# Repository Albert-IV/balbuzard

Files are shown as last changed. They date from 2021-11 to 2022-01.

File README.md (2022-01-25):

# Balbuzard

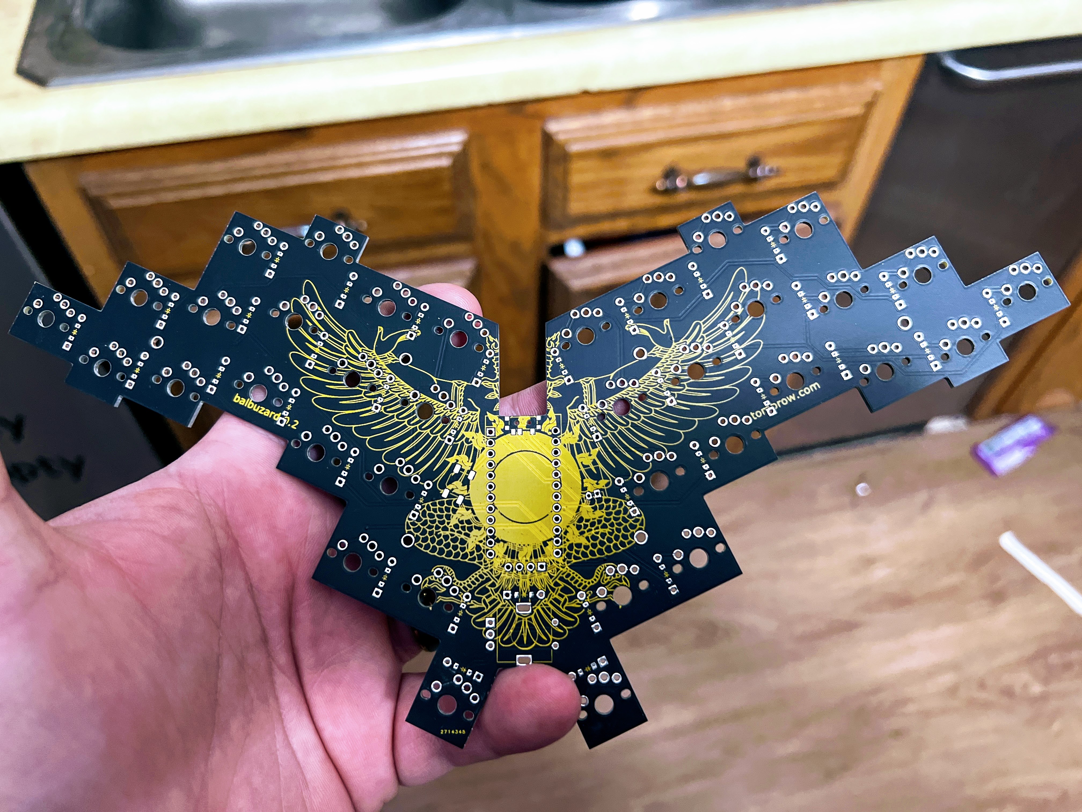
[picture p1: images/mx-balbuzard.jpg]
photo of assembled keyboard


Balbuzard is a 36-key keyboard with a PCB. This repository contains the [Ergogen](https://github.com/mrzealot/ergogen) configuration that generates the KiCad PCB file.

## Usage

Assuming you have [npm installed](https://www.npmjs.com/get-npm):

``` sh
git clone --recursive git@github.com:brow/balbuzard.git
cd balbuzard
make
```

Find the generated PCB at `output/pcbs/main.kicad_pcb`.

pcb thumbnail image

## How do you type on that?

My keymap looks like this. The colors indicate which finger I use to hit each key.

example keymap

## Rev 1.

* Ergogen config upgraded to latest 3.0.0
* Column layout tweaked, ready for routuing
* Each key / diode is routed.  Next is to route columns and rows (AKA the hard part)
* Removed routing done since I've found a way in Kicad to make direct connections (which will make the key routing cleaner looking)
* Redid the key / diode routing to use straight tracks wherever I could. 
* Just went ahead and used [an autorouter called Freerouter.](https://github.com/freerouting/freerouting/)
* After much gnashing of teeth, I have the scales SVG working.  Now to add to the front / back of PCB.

Front SVG Export:
Edge.Cuts
F.Silkscreen
F.Mask

Back SVG Export:
Edge.Cuts
B.Silkscreen
B.Mask

# TODO

* Add Balbuzard silkscreen on the front of the PCB
* Add something to the back of the PCB?  Thinking maybe a pattern like this: https://pattern.monster/scales-3/

**Note:** If there is a Rev 2. you will need to rotate the left side buttom-most thumb key's diode.  Rotated manually in Kicad to make it easier to route without routing on the back side.

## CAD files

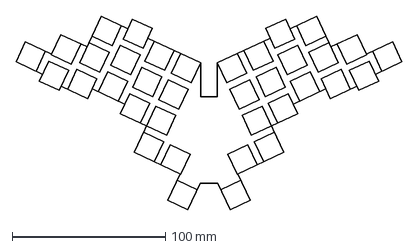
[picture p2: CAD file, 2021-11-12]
output/outlines/mockup.dxf
251.9 x 126.1 mm

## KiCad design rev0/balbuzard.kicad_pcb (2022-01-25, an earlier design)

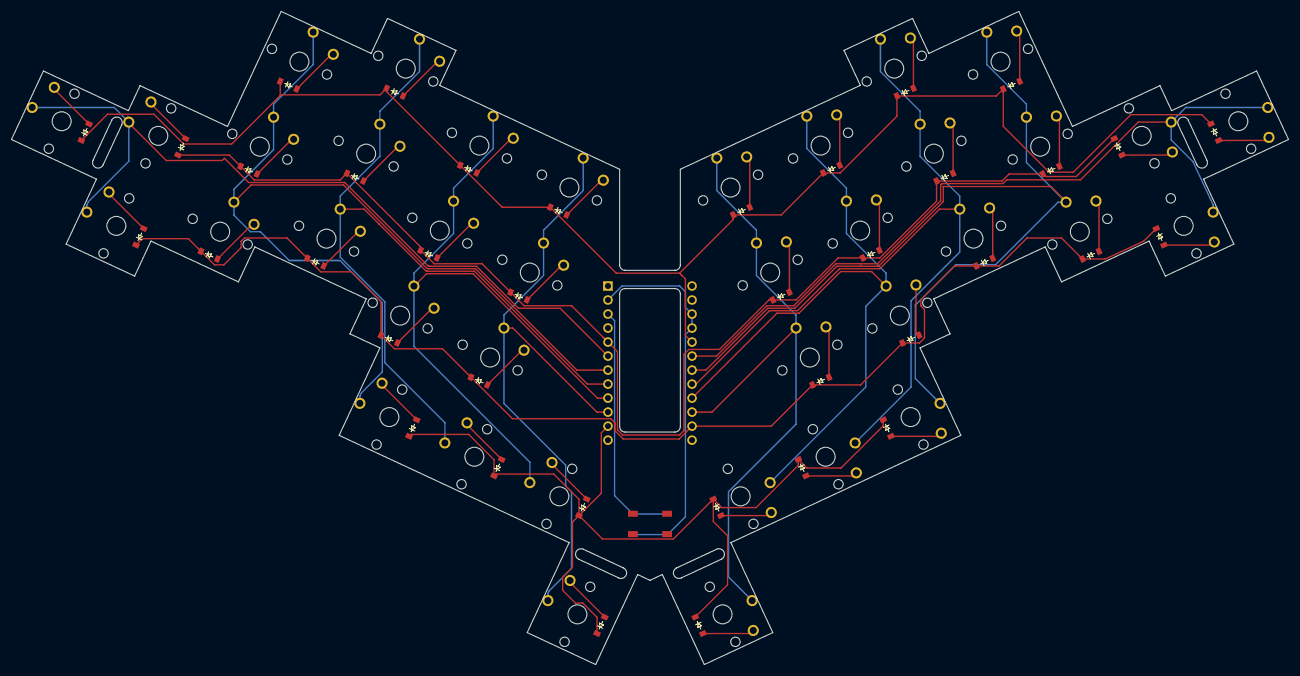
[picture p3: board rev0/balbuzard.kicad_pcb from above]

Board: 2 copper layers, 231.5 x 118.4 mm, 77 parts (0 on the bottom side), 52 nets.

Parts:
B1: SW_TACT_ALPS_SKQGABE010
D1, D2, D3, D4, D5, D6, D7, D8, D9, D10, D11, D12, D13, D14, D15, D16, D17, D18, D19, D20, D21, D22, D23, D24, D25, D26, D27, D28, D29, D30, D31, D32, D33, D34, D35, D36, D37, D38: ComboDiode
S1, S2, S3, S4, S5, S6, S7, S8, S9, S10, S11, S12, S13, S14, S15, S16, S17, S18, S19, S20, S21, S22, S23, S24, S25, S26, S27, S28, S29, S30, S31, S32, S33, S34, S35, S36, S37, S38: PG1350

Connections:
P2: D3.1, D6.1, D9.1, D12.1, D15.1, D22.1, D25.1, D28.1, D31.1, D34.1
P3: S20.2, S21.2, S22.2
P4: S23.2, S24.2, S25.2, S35.2
P5: S26.2, S27.2, S28.2, S36.2
P6: S29.2, S30.2, S31.2, S37.2
P7: S32.2, S33.2, S34.2, S38.2
P8: D1.1, D4.1, D7.1, D10.1, D13.1, D20.1, D23.1, D26.1, D29.1, D32.1
P14: S13.2, S14.2, S15.2, S19.2
P15: S10.2, S11.2, S12.2, S18.2
P16: D16.1, D17.1, D18.1, D19.1, D35.1, D36.1, D37.1, D38.1
P18: S7.2, S8.2, S9.2, S17.2
P19: S4.2, S5.2, S6.2, S16.2
P20: S1.2, S2.2, S3.2
P21: D2.1, D5.1, D8.1, D11.1, D14.1, D21.1, D24.1, D27.1, D30.1, D33.1
far_thumb: D19.2, S19.1
home_thumb: D18.2, S18.1
index_bottom: D10.2, S10.1
index_home: D11.2, S11.1
index_top: D12.2, S12.1
inner_bottom: D13.2, S13.1
inner_home: D14.2, S14.1
inner_top: D15.2, S15.1
middle_bottom: D7.2, S7.1
middle_home: D8.2, S8.1
middle_top: D9.2, S9.1
mirror_far_thumb: D38.2, S38.1
mirror_home_thumb: D37.2, S37.1
mirror_index_bottom: D29.2, S29.1
mirror_index_home: D30.2, S30.1
mirror_index_top: D31.2, S31.1
mirror_inner_bottom: D32.2, S32.1
mirror_inner_home: D33.2, S33.1
mirror_inner_top: D34.2, S34.1
mirror_middle_bottom: D26.2, S26.1
mirror_middle_home: D27.2, S27.1
mirror_middle_top: D28.2, S28.1
mirror_near_thumb: D36.2, S36.1
mirror_nearer_thumb: D35.2, S35.1
mirror_pinky_bottom: D20.2, S20.1
mirror_pinky_home: D21.2, S21.1
mirror_pinky_top: D22.2, S22.1
mirror_ring_bottom: D23.2, S23.1
mirror_ring_home: D24.2, S24.1
mirror_ring_top: D25.2, S25.1
near_thumb: D17.2, S17.1
nearer_thumb: D16.2, S16.1
pinky_bottom: D1.2, S1.1
pinky_home: D2.2, S2.1
pinky_top: D3.2, S3.1
ring_bottom: D4.2, S4.1
ring_home: D5.2, S5.1
ring_top: D6.2, S6.1

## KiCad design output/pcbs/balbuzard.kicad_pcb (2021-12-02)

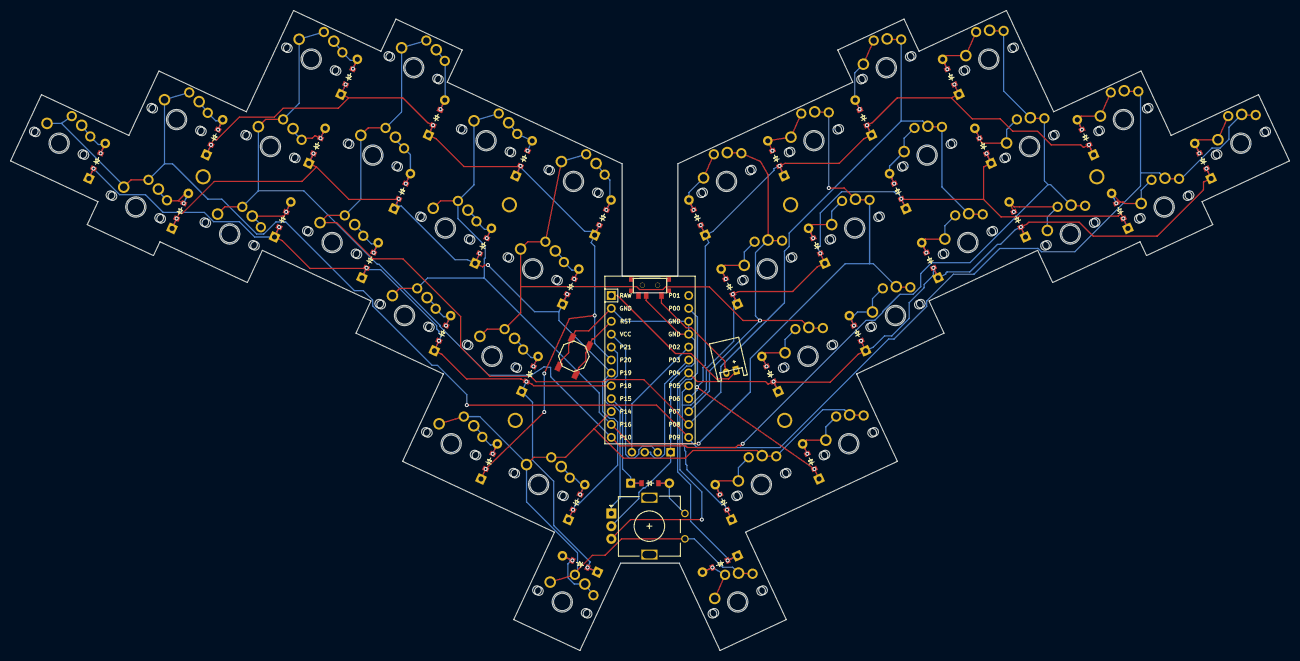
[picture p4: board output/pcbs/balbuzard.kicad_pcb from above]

Board: 2 copper layers, 251.9 x 126.1 mm, 121 parts (0 on the bottom side), 59 nets.

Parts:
B1: SW_TACT_ALPS_SKQGABE010
D1, D2, D3, D4, D5, D6, D7, D8, D9, D10, D11, D12, D13, D14, D15, D16, D17, D18, D19, D20, D21, D22, D23, D24, D25, D26, D27, D28, D29, D30, D31, D32, D33, D34, D35, D36, D37: ComboDiode
HOLE1, HOLE2, HOLE3, HOLE4, HOLE5, HOLE6: MountingHole_2.2mm_M2_Pad_Via
JST1: JST_PH_S2B-PH-K_02x2.00mm_Angled
MCU1: ProMicro
OLED1: OLED; OLED_headers
ROT1: rotary_encoder
S1, S3, S5, S7, S9, S11, S13, S15, S17, S19, S21, S23, S25, S27, S29, S31, S33, S35, S37, S39, S41, S43, S45, S47, S49, S51, S53, S55, S57, S59, S61, S63, S65, S67, S69, S71: MX
S2, S4, S6, S8, S10, S12, S14, S16, S18, S20, S22, S24, S26, S28, S30, S32, S34, S36, S38, S40, S42, S44, S46, S48, S50, S52, S54, S56, S58, S60, S62, S64, S66, S68, S70, S72: PG1350
T1: SPDT_C128955

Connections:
GND: B1.2, MCU1.2, MCU1.15, MCU1.16, OLED1.1, ROT1.C, T1.2
P0: MCU1.14, ROT1.B
P2: MCU1.17, OLED1.4
P3: MCU1.18, OLED1.3
P4: D19.1, D19.2, D22.1, D22.2, D25.1, D25.2, D28.1, D28.2, D31.1, D31.2, D36.1, D36.2, MCU1.19
P5: D20.1, D20.2, D23.1, D23.2, D26.1, D26.2, D29.1, D29.2, D32.1, D32.2, D35.1, D35.2, MCU1.20
P6: D21.1, D21.2, D24.1, D24.2, D27.1, D27.2, D30.1, D30.2, D33.1, D33.2, D34.1, D34.2, MCU1.21
P7: MCU1.22, S25.2, S26.2, S27.2, S28.2, S29.2, S30.2, S61.1, S62.1, S63.1, S64.1, S65.1, S66.1
P8: MCU1.23, S13.2, S14.2, S15.2, S16.2, S17.2, S18.2, S49.1, S50.1, S51.1, S52.1, S53.1, S54.1
P9: MCU1.24, S1.2, S2.2, S3.2, S4.2, S5.2, S6.2, S37.1, S38.1, S39.1, S40.1, S41.1, S42.1
P10: MCU1.12, S7.2, S8.2, S9.2, S10.2, S11.2, S12.2, S43.1, S44.1, S45.1, S46.1, S47.1, S48.1
P14: MCU1.10, ROT1.2, S31.2, S32.2, S33.2, S34.2, S35.2, S36.2, S67.1, S68.1, S69.1, S70.1, S71.1, S72.1
P15: D37.1, D37.2, MCU1.9
P16: MCU1.11, S19.2, S20.2, S21.2, S22.2, S23.2, S24.2, S55.1, S56.1, S57.1, S58.1, S59.1, S60.1
P18: D1.1, D1.2, D4.1, D4.2, D7.1, D7.2, D10.1, D10.2, D13.1, D13.2, D18.1, D18.2, MCU1.8
P19: D2.1, D2.2, D5.1, D5.2, D8.1, D8.2, D11.1, D11.2, D14.1, D14.2, D17.1, D17.2, MCU1.7
P20: D3.1, D3.2, D6.1, D6.2, D9.1, D9.2, D12.1, D12.2, D15.1, D15.2, D16.1, D16.2, MCU1.6
P21: MCU1.5, ROT1.A
RAW: JST1.1, MCU1.1
RST: B1.1, MCU1.3
VCC: MCU1.4, OLED1.2
far_thumb: D18.1, D18.2, S35.1, S36.1
home_thumb: D17.1, D17.2, S33.1, S34.1
index_bottom: D10.1, D10.2, S19.1, S20.1
index_home: D11.1, D11.2, S21.1, S22.1
index_top: D12.1, D12.2, S23.1, S24.1
inner_bottom: D13.1, D13.2, S25.1, S26.1
inner_home: D14.1, D14.2, S27.1, S28.1
inner_top: D15.1, D15.2, S29.1, S30.1
middle_bottom: D7.1, D7.2, S13.1, S14.1
middle_home: D8.1, D8.2, S15.1, S16.1
middle_top: D9.1, D9.2, S17.1, S18.1
mirror_far_thumb: D36.1, D36.2, S71.2, S72.2
mirror_home_thumb: D35.1, D35.2, S69.2, S70.2
mirror_index_bottom: D28.1, D28.2, S55.2, S56.2
mirror_index_home: D29.1, D29.2, S57.2, S58.2
mirror_index_top: D30.1, D30.2, S59.2, S60.2
mirror_inner_bottom: D31.1, D31.2, S61.2, S62.2
mirror_inner_home: D32.1, D32.2, S63.2, S64.2
mirror_inner_top: D33.1, D33.2, S65.2, S66.2
mirror_middle_bottom: D25.1, D25.2, S49.2, S50.2
mirror_middle_home: D26.1, D26.2, S51.2, S52.2
mirror_middle_top: D27.1, D27.2, S53.2, S54.2
mirror_near_thumb: D34.1, D34.2, S67.2, S68.2
mirror_pinky_bottom: D19.1, D19.2, S37.2, S38.2
mirror_pinky_home: D20.1, D20.2, S39.2, S40.2
mirror_pinky_top: D21.1, D21.2, S41.2, S42.2
mirror_ring_bottom: D22.1, D22.2, S43.2, S44.2
mirror_ring_home: D23.1, D23.2, S45.2, S46.2
mirror_ring_top: D24.1, D24.2, S47.2, S48.2
near_thumb: D16.1, D16.2, S31.1, S32.1
pinky_bottom: D1.1, D1.2, S1.1, S2.1
pinky_home: D2.1, D2.2, S3.1, S4.1
pinky_top: D3.1, D3.2, S5.1, S6.1
ring_bottom: D4.1, D4.2, S7.1, S8.1
ring_home: D5.1, D5.2, S9.1, S10.1
ring_top: D6.1, D6.2, S11.1, S12.1
rotary_diode: D37.1, D37.2, ROT1.1
slider_positive: JST1.2, T1.1

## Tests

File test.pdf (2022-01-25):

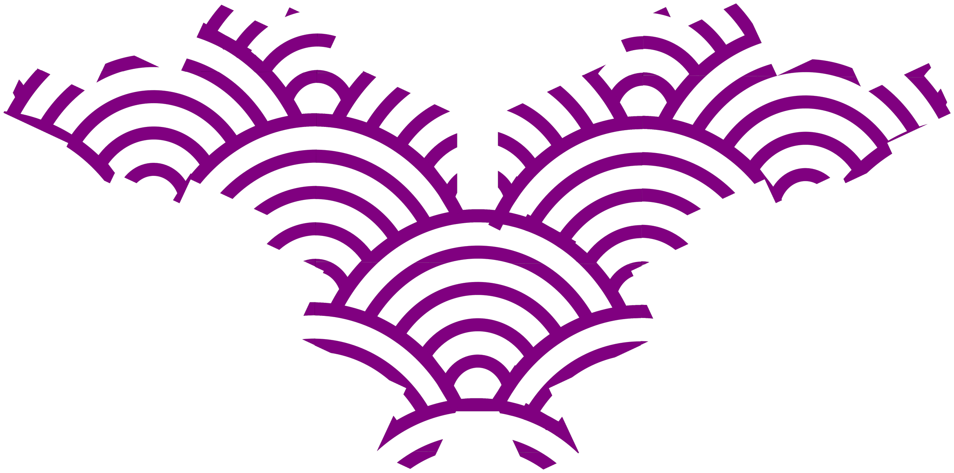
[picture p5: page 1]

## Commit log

2021-11-11 Began work on routing and updating dependencies. Right now both make and npm can compile, will probably remove the Makefile eventually. Had a couple of nice tweaks I might submit a PR for
    [main.kicad_pcb, mockup.dxf]
2021-11-12 Also commit this too
    [main.kicad_pcb, mockup.dxf]
2021-11-23 Routing fixed, added encoder and on / off switch. Last that is left is JST connector and reset button
    [main.kicad_pcb]
2021-11-23 Added reset button
    [main.kicad_pcb]
2021-11-23 Flipped the JST connector to be correct
    [main.kicad_pcb]
2021-11-30 Mounting holes: Added
    [main.kicad_pcb]
2021-11-30 Create rev1 directory, time to begin routing!
    [balbuzard.kicad_pcb]
2021-11-30 Fix issue with thumb mirror not reversing switch pins
    [balbuzard.kicad_pcb]
2021-12-01 Routed individual keys, added info on progress
    [balbuzard.kicad_pcb]
2021-12-01 Removed routing, found a better way
    [balbuzard.kicad_pcb]
2021-12-01 Redid the key / diode tracks to be as straight as possible.
    [balbuzard.kicad_pcb]
2021-12-02 Went ahead and used an autorouter to do traces. Did 90% of the work for me (hopefully)
    [balbuzard.dsn, balbuzard.kicad_pcb]
2021-12-05 Added waves SVG for silkscreens and added a copper fill.
2022-01-25 Finished Rev1 PCB and sent off to be manufactured. Repo is in need of a huge cleanup effort
2022-01-25 Finished Rev1 PCB and sent off to be manufactured. Repo is in need of a huge cleanup effort
    Add photo of PCB
    Removed svg2shenzen cache items
    Removed svg2shenzen cache items
    Added svg2shenzen cache to git ignore
    [balbuzard-B_Cu.gbl, balbuzard-B_Mask.gbs, balbuzard-B_Paste.gbp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]
